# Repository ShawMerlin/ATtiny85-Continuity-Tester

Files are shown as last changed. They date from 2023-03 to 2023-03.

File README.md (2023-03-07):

# ATtiny85-Continuity-Tester

The lack of good quality Continuity Testers is shocking.  Even some of the more expensives ones are terrible. <br />
False Alarms and the potential of damaging sensitive equipment have to be looked at as well. <br />

I found this ATtiny Continuity Tester schematic from https://github.com/technoblogy/continuity-tester  <br /> 
Having an easy to assembly kit for DIYers was also considered in the creation of this PCB. <br />



ATtiny85 Program Code can be found here:  http://www.technoblogy.com/list?1ZNS <br />

It is set to go into sleep mode after 1 minute to save battery power. <br />
in Sleep Mode, the LED will be powered off and will wake again when the leads touch. <br /> 
A power switch was also included so that it can be stored for longer periods of time. <br />

Not wanting to replace batteries often, I included a dual 18650 holder that has both batteries in parallel. <br />
The 18650 Batteries will literally self-discharge before being used up by this circuit.  <br />

Project is completely open source with Kicad files to be provided.  This can be modified to your hears desire. <br />

More Content Like this - www.facebook.com/GeekIslandGaming  <br />



All Donations are reinvested into ideas and projects. Thank you for the support!! <br /> <br />

Here is a blown up picture of this board with things removed to make it easier to see what parts go where. <br />



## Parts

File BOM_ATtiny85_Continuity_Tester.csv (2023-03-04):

Ref | Val | Model | Mouser
BATT1 | 18650 Battery Holder | 1048P | https://www.mouser.com/ProductDetail/Keystone-Electronics/1048P?qs=9%252Bwcgl%2FJqd1h8Vx3IFpTxA%3D%3D
C1 | .1uF | FA26NP01H104JNU06 | https://www.mouser.com/ProductDetail/TDK/FA26NP01H104JNU06?qs=UrFqKgNWc7RkUDHb07EBLQ%3D%3D
D1 | Blue LED | OVLLB8C7 | https://www.mouser.com/ProductDetail/Optek-TT-Electronics/OVLLB8C7?qs=Dz6MBz%252BjnkGU%2F0vuidjXSQ%3D%3D
D2 | Red | OVLLR8C7 | https://www.mouser.com/ProductDetail/Optek-TT-Electronics/OVLLR8C7?qs=SXXRyeEQT0mqxCGQ0ZD1Zg%3D%3D
D3,D4 | Diodes | MBR150RLG | https://www.mouser.com/ProductDetail/onsemi/MBR150RLG?qs=3JMERSakebpMUdfDTQP0Kw%3D%3D
J1 | Red Vertical Probe | 6037 | https://www.mouser.com/ProductDetail/Keystone-Electronics/6037?qs=RfgnRl00reQ%2FAdfdXZ%2FHVQ%3D%3D
J2 | Black Vertical Probe | 6038 | https://www.mouser.com/ProductDetail/Keystone-Electronics/6038?qs=RfgnRl00reRe9nxm0w%252B40Q%3D%3D
J3 | Red Horizontal Probe | 105-0752-001 | https://www.mouser.com/ProductDetail/Johnson-Cinch-Connectivity-Solutions/105-0752-001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
J4 | Black Horizontal Probe | 105-0753-001 | https://www.mouser.com/ProductDetail/Johnson-Cinch-Connectivity-Solutions/105-0753-001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
J5 | Switch | OS102011MS2QN1 | https://www.mouser.com/ProductDetail/CK/OS102011MS2QN1?qs=WtljUlYws5RvQ1hEv876nQ%3D%3D
LS1 | Buzzer | CST-931RP-A | https://www.mouser.com/ProductDetail/CUI-Devices/CST-931RP-A?qs=WyjlAZoYn53DKTeYch4Tww%3D%3D
R1,R3 | 1K | CFR-25JR-52-1K | https://www.mouser.com/ProductDetail/YAGEO/CFR-25JR-52-1K?qs=FK4oyhsNhknmd5zXOZ4mTQ%3D%3D
R2 | 51R | CFR-25JR-52-51R | https://www.mouser.com/ProductDetail/YAGEO/CFR-25JR-52-51R?qs=acBVhj9v9XXTvO3QTSPhHA%3D%3D
U1 | Microcontroller | ATTINY85-20PU | https://www.mouser.com/ProductDetail/Microchip-Technology-Atmel/ATTINY85-20PU?qs=8jWQYweyg6NCiiaOb5GI9Q%3D%3D

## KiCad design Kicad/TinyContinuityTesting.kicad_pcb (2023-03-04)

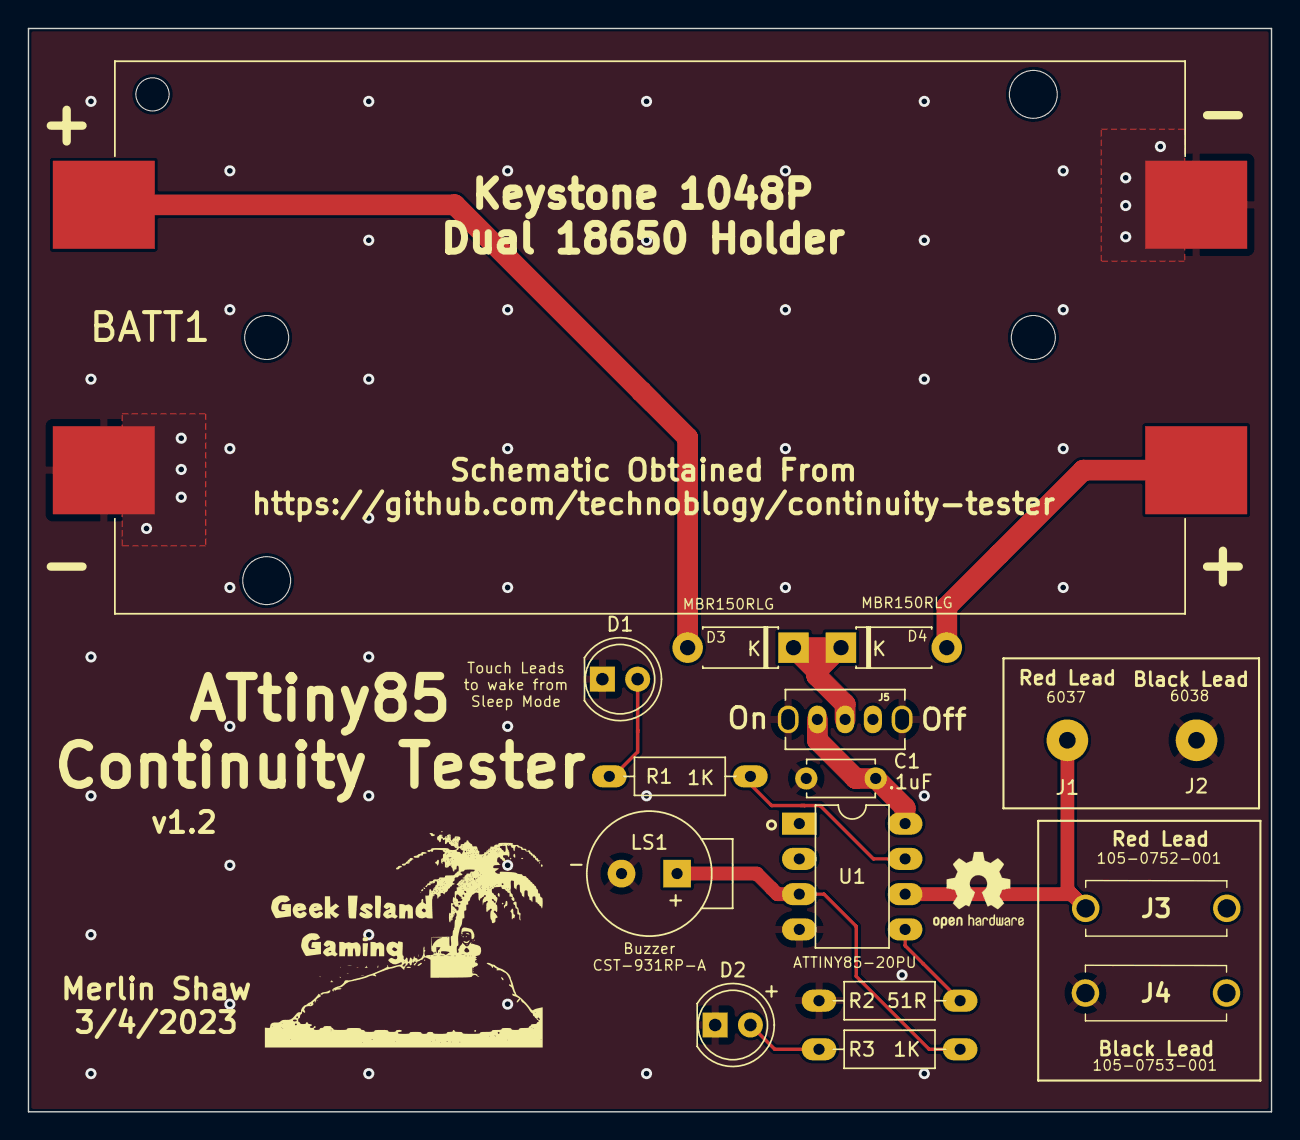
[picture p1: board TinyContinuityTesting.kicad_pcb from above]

Board: 2 copper layers, 89.5 x 78.0 mm, 16 parts (0 on the bottom side), 10 nets.

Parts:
BATT1: BAT_1048P
C1: .1uF; C_Disc_D4.7mm_W2.5mm_P5.00mm
D1, D2: LED_D5.0mm
D3, D4: D_DO-41_SOD81_P7.62mm_Horizontal
J1, J2: PinHeader_1x01_P2.54mm_Vertical
J3: Probe; 1050752001
J4: Gnd; 1050752001
J5: Conn_01x03; SW_OS102011MS2QN1
LS1: Buzzer_CUI_CST-931RP-A
R1, R3: 2.7K; R_Axial_DIN0207_L6.3mm_D2.5mm_P10.16mm_Horizontal
R2: 51R; R_Axial_DIN0207_L6.3mm_D2.5mm_P10.16mm_Horizontal
U1: ATtiny85-20S; DIP-8_W7.62mm

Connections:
3V: C1.1, J5.1, U1.8 (VCC)
22: D1.2 (A), R1.1
333: D3.1, D4.1, J5.2
+3.3V: D3.2, D4.2
GND: BATT1.1-, BATT1.2-, C1.2, D1.1 (K), D2.1 (K), J2.1, J4.1, LS1.M, R2.1, U1.4 (GND)
unnamed: D2.2 (A), R3.2
unnamed: J1.1, J3.1, U1.6 (PB1)
unnamed: R2.2, U1.5 (AREF/PB0)
unnamed: R1.2, U1.7 (PB2)
unnamed: LS1.P, R3.1, U1.3 (XTAL2/PB4)
